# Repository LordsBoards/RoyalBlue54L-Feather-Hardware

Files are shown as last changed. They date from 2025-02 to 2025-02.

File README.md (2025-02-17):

# RoyalBlue54L Feather

An ARM + RISC-V Feather board with the new nRF54L15, built-in debugger, and smart PMIC

<p align="center">
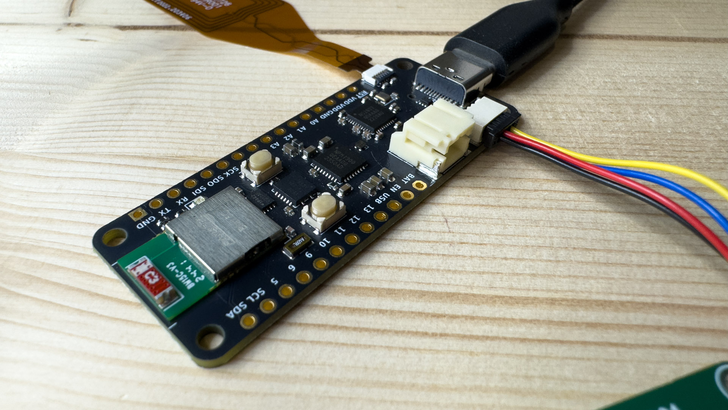
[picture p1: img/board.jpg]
RoyalBlue54L Feather
  
</p>

## Overview

The RoyalBlue54L--familiar Feather formfactor with distinctive features. Nordic's next-gen nRF54L15, an onboard CMSIS-DAP debugger + UART bridge, and smart power-management features from the nPM1300 enable rapid development for your next Bluetooth 6.0, Thread, Matter, Zigbee, Amazon Sidewalk, or proprietary wireless project.

Pre-launch on Crowd Supply - More details coming soon!

## Hardware Features

* Dual-core processing power:
  * ARM Cortex-M33 at 128MHz
  * RISC-V co-processor at 128MHz
* Comprehensive memory configuration:
  * 1.5MB of non-volatile memory (NVM)
  * 256KB of RAM
  * 2MB external flash
* Advanced wireless capabilities:
  * BLE 6.0 support with channel sounding for distance estimation
  * 4Mbps PHY for proprietary wireless protocols
  * 30-50% power reduction compared to nRF52 series
* Integrated development tools:
  * CMSIS-DAP debugger (nRF52833-based)
  * USB-to-UART bridge
  * Open source, Zephyr RTOS-based firmware
* Smart power management:
  * USB-C charging up to 800mA with nPM1300
  * High-accuracy battery fuel gauge
* Connectivity:
  * JST-PH connector
  * STEMMA-QT/Qwiic port
  * NFC antenna connector
* User interfaces:
  * User LED
  * RGB LED (nPM1300-driven)
  * User button
  * Reset button

## Repository Contents

This repository contains the hardware design files for the RoyalBlue54L Feather. The board is designed with KiCAD and includes:

* Schematic files
* PCB layout
* Bill of Materials (BOM)
* Manufacturing files
* Documentation

## Pinout

<p align="center">
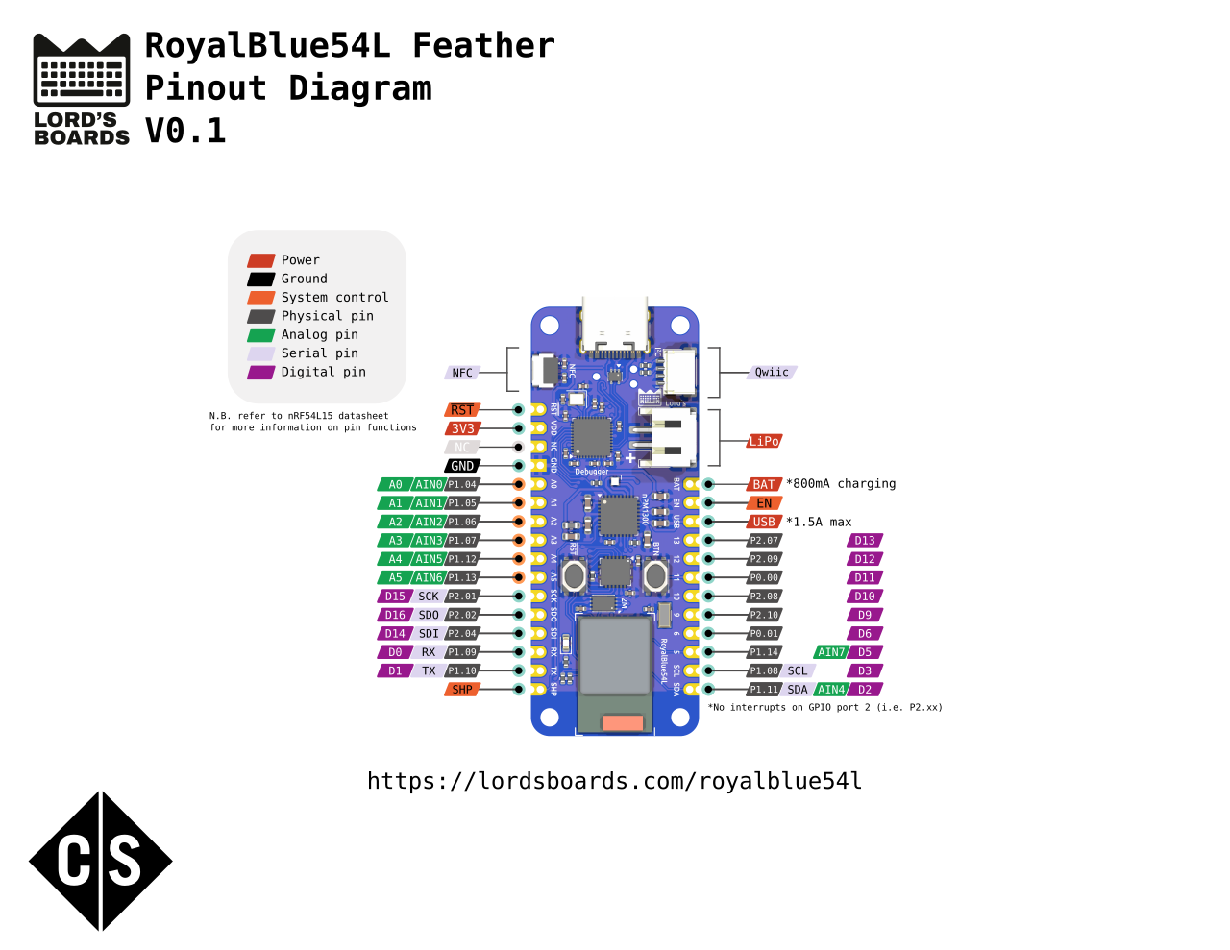
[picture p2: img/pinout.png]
RoyalBlue54L Pinout
    
</p>

## Related Repositories

* [Zephyr Board Support](https://github.com/LordsBoards/RoyalBlue-nRF54L15-Zephyr-Boards)
* [Debugger Firmware](https://github.com/LordsBoards/RoyalBlue-nRF54L15-Debugger-Firmware)

## License

Hardware files are released under CERN-OHL-V2-P.

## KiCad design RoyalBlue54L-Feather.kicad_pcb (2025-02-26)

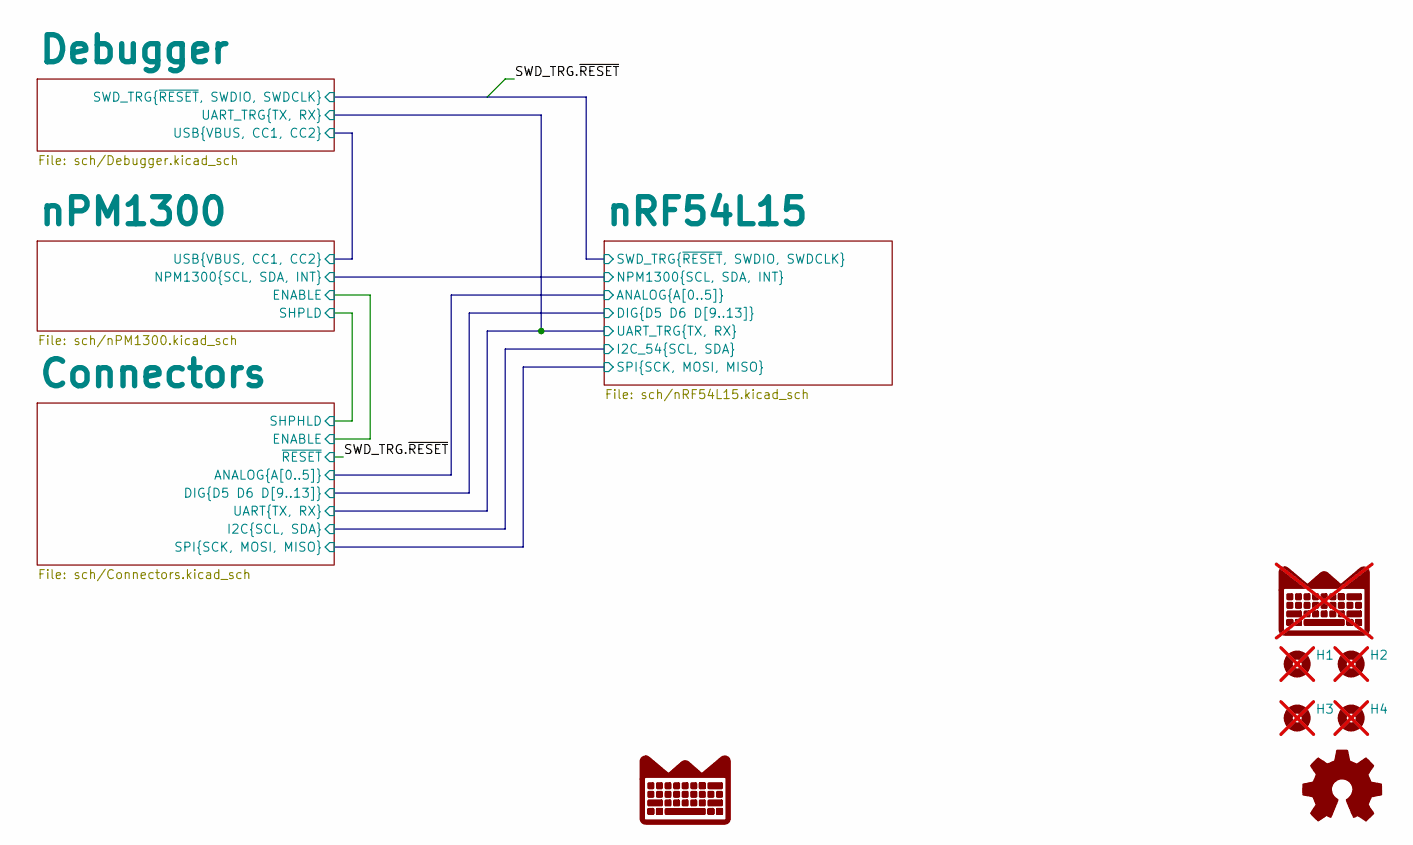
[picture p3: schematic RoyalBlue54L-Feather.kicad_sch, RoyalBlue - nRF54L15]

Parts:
H1, H2, H3, H4: MountingHole; MountingHole_2.5mm; not fitted
LOGO1: LordsBoardsLogo_Small_Silk; not fitted

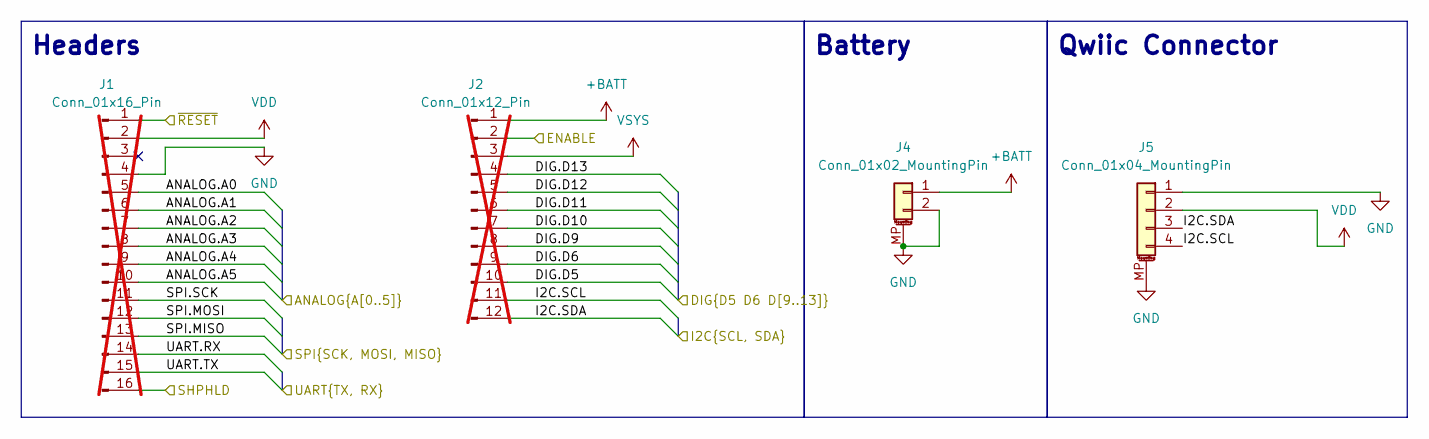
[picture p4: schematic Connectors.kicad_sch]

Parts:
J1: Conn_01x16_Pin; PinHeader_1x16_P2.54mm_Vertical; not fitted
J2: Conn_01x12_Pin; PinHeader_1x12_P2.54mm_Vertical; not fitted
J4: Conn_01x02_MountingPin; JST_PH_S2B-PH-SM4-TB_1x02-1MP_P2.00mm_Horizontal; LCSC C295747
J5: Conn_01x04_MountingPin; JST_SH_SM04B-SRSS-TB_1x04-1MP_P1.00mm_Horizontal; LCSC C3029343

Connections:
+BATT: J2.1, J4.1; also elsewhere on the board
/Connectors/ANALOG.A0: J1.5; also elsewhere on the board
/Connectors/ANALOG.A1: J1.6; also elsewhere on the board
/Connectors/ANALOG.A2: J1.7; also elsewhere on the board
/Connectors/ANALOG.A3: J1.8; also elsewhere on the board
/Connectors/ANALOG.A4: J1.9; also elsewhere on the board
/Connectors/ANALOG.A5: J1.10; also elsewhere on the board
/Connectors/DIG.D5: J2.10; also elsewhere on the board
/Connectors/DIG.D6: J2.9; also elsewhere on the board
/Connectors/DIG.D9: J2.8; also elsewhere on the board
/Connectors/DIG.D10: J2.7; also elsewhere on the board
/Connectors/DIG.D11: J2.6; also elsewhere on the board
/Connectors/DIG.D12: J2.5; also elsewhere on the board
/Connectors/DIG.D13: J2.4; also elsewhere on the board
/Connectors/ENABLE: J2.2; also elsewhere on the board
/Connectors/I2C.SCL: J2.11, J5.4; also elsewhere on the board
/Connectors/I2C.SDA: J2.12, J5.3; also elsewhere on the board
/Connectors/SHPHLD: J1.16; also elsewhere on the board
/Connectors/SPI.MISO: J1.13; also elsewhere on the board
/Connectors/SPI.MOSI: J1.12; also elsewhere on the board
/Connectors/SPI.SCK: J1.11; also elsewhere on the board
/Connectors/UART.RX: J1.14; also elsewhere on the board
/Connectors/UART.TX: J1.15; also elsewhere on the board
/Debugger/SWD_TRG.~RESET: J1.1; also elsewhere on the board
GND: J1.4, J4.2, J4.MP (MountPin), J5.1, J5.MP (MountPin); also elsewhere on the board
VDD: J1.2, J5.2; also elsewhere on the board
VSYS: J2.3; also elsewhere on the board

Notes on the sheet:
Qwiic Connector
Battery
Headers

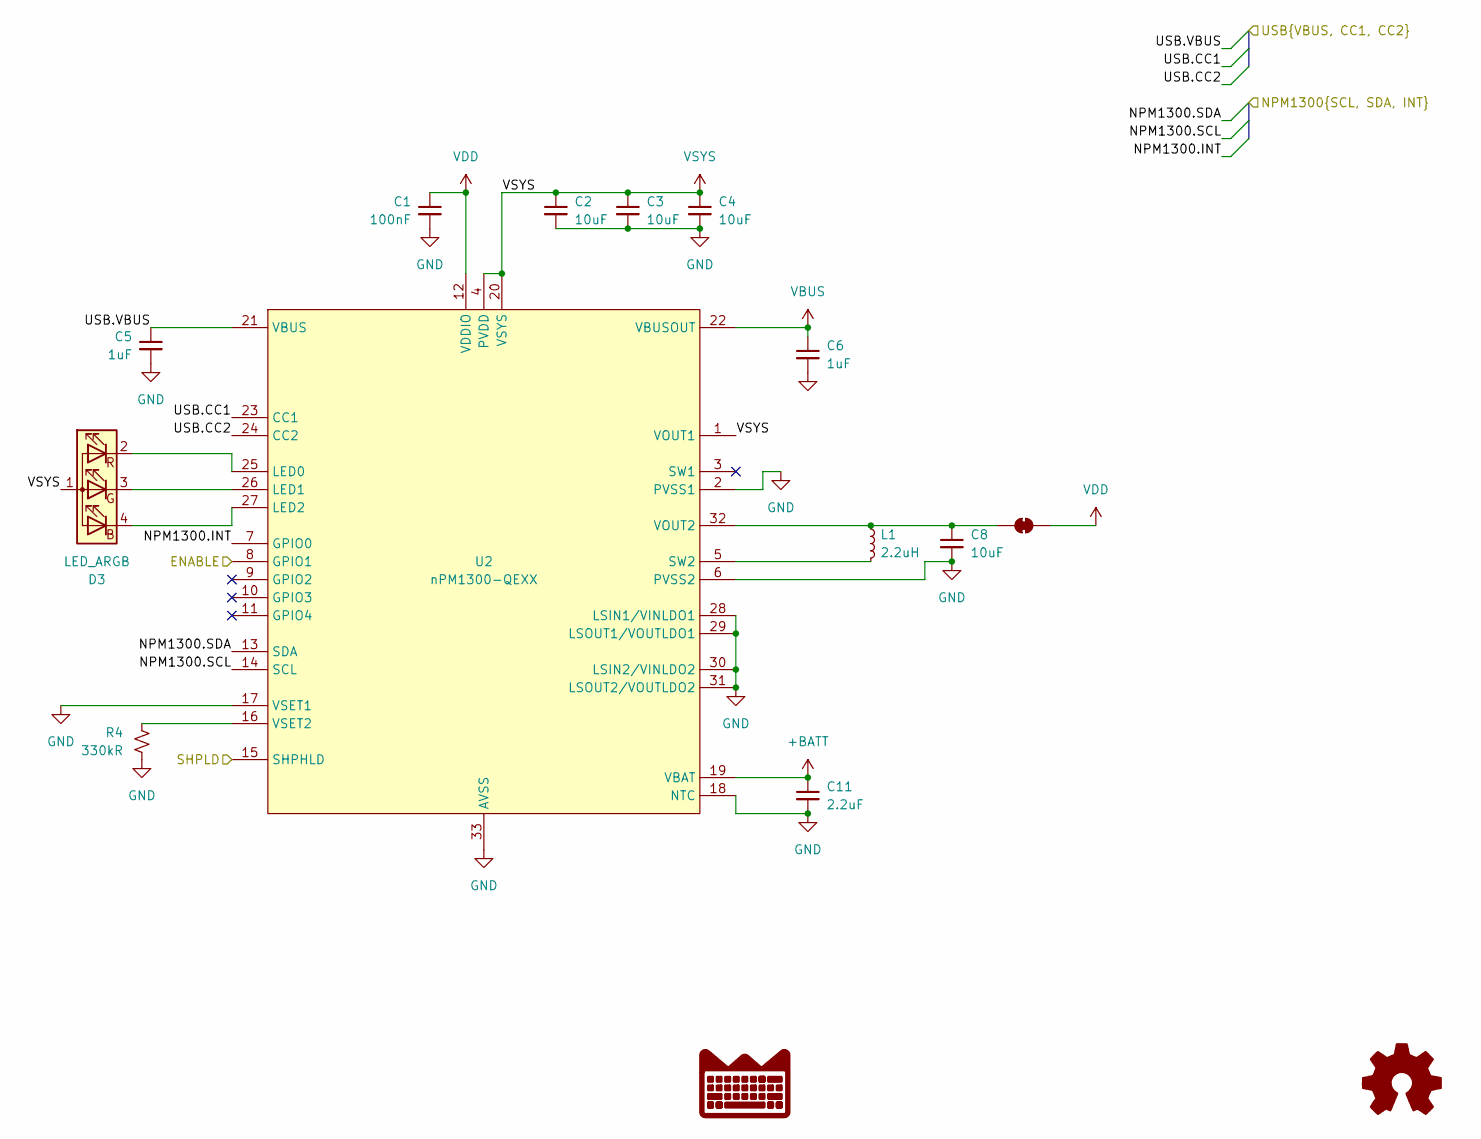
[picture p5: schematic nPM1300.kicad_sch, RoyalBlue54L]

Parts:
C1: 100nF; C_0402_1005Metric; LCSC C307331
C2, C3, C4, C8: 10uF; C_0603_1608Metric; LCSC C96446
C5, C6: 1uF; C_0603_1608Metric; LCSC C15849
C11: 2.2uF; C_0603_1608Metric; LCSC C23630
D3: LED_ARGB; LED_Wurth_150044M155260; LCSC C404280
JP1: SolderJumper_2_Bridged; SolderJumper-2_P1.3mm_Bridged_RoundedPad1.0x1.5mm
L1: 2.2uH; L_0603_1608Metric; LCSC C337910
R4: 330kR; R_0402_1005Metric; LCSC C25778
U2: nPM1300-QEXX; QFN-32-1EP_5x5mm_P0.5mm_EP3.6x3.6mm_ThermalVias; LCSC C7466043

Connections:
+BATT: C11.1, U2.19 (VBAT); also elsewhere on the board
/Connectors/ENABLE: U2.8 (GPIO1); also elsewhere on the board
/Connectors/SHPHLD: U2.15 (SHPHLD); also elsewhere on the board
/Debugger/USB.CC1: U2.23 (CC1); also elsewhere on the board
/Debugger/USB.CC2: U2.24 (CC2); also elsewhere on the board
/Debugger/USB.VBUS: C5.1, U2.21 (VBUS); also elsewhere on the board
/nPM1300/NPM1300.INT: U2.7 (GPIO0); also elsewhere on the board
/nPM1300/NPM1300.SCL: U2.14 (SCL); also elsewhere on the board
/nPM1300/NPM1300.SDA: U2.13 (SDA); also elsewhere on the board
GND: C1.2, C2.2, C3.2, C4.2, C5.2, C6.2, C8.2, C11.2, R4.2, U2.2 (PVSS1), U2.6 (PVSS2), U2.17 (VSET1), U2.18 (NTC), U2.28 (LSIN1/VINLDO1), U2.29 (LSOUT1/VOUTLDO1), U2.30 (LSIN2/VINLDO2), U2.31 (LSOUT2/VOUTLDO2), U2.33 (AVSS); also elsewhere on the board
unnamed: D3.4 (BK), U2.27 (LED2)
unnamed: D3.3 (GK), U2.26 (LED1)
unnamed: D3.2 (RK), U2.25 (LED0)
unnamed: C8.1, JP1.1 (A), L1.1, U2.32 (VOUT2)
unnamed: L1.2, U2.5 (SW2)
unnamed: R4.1, U2.16 (VSET2)
VBUS: C6.1, U2.22 (VBUSOUT); also elsewhere on the board
VDD: C1.1, JP1.2 (B), U2.12 (VDDIO); also elsewhere on the board
VSYS: C2.1, C3.1, C4.1, D3.1 (A), U2.1 (VOUT1), U2.4 (PVDD), U2.20 (VSYS); also elsewhere on the board

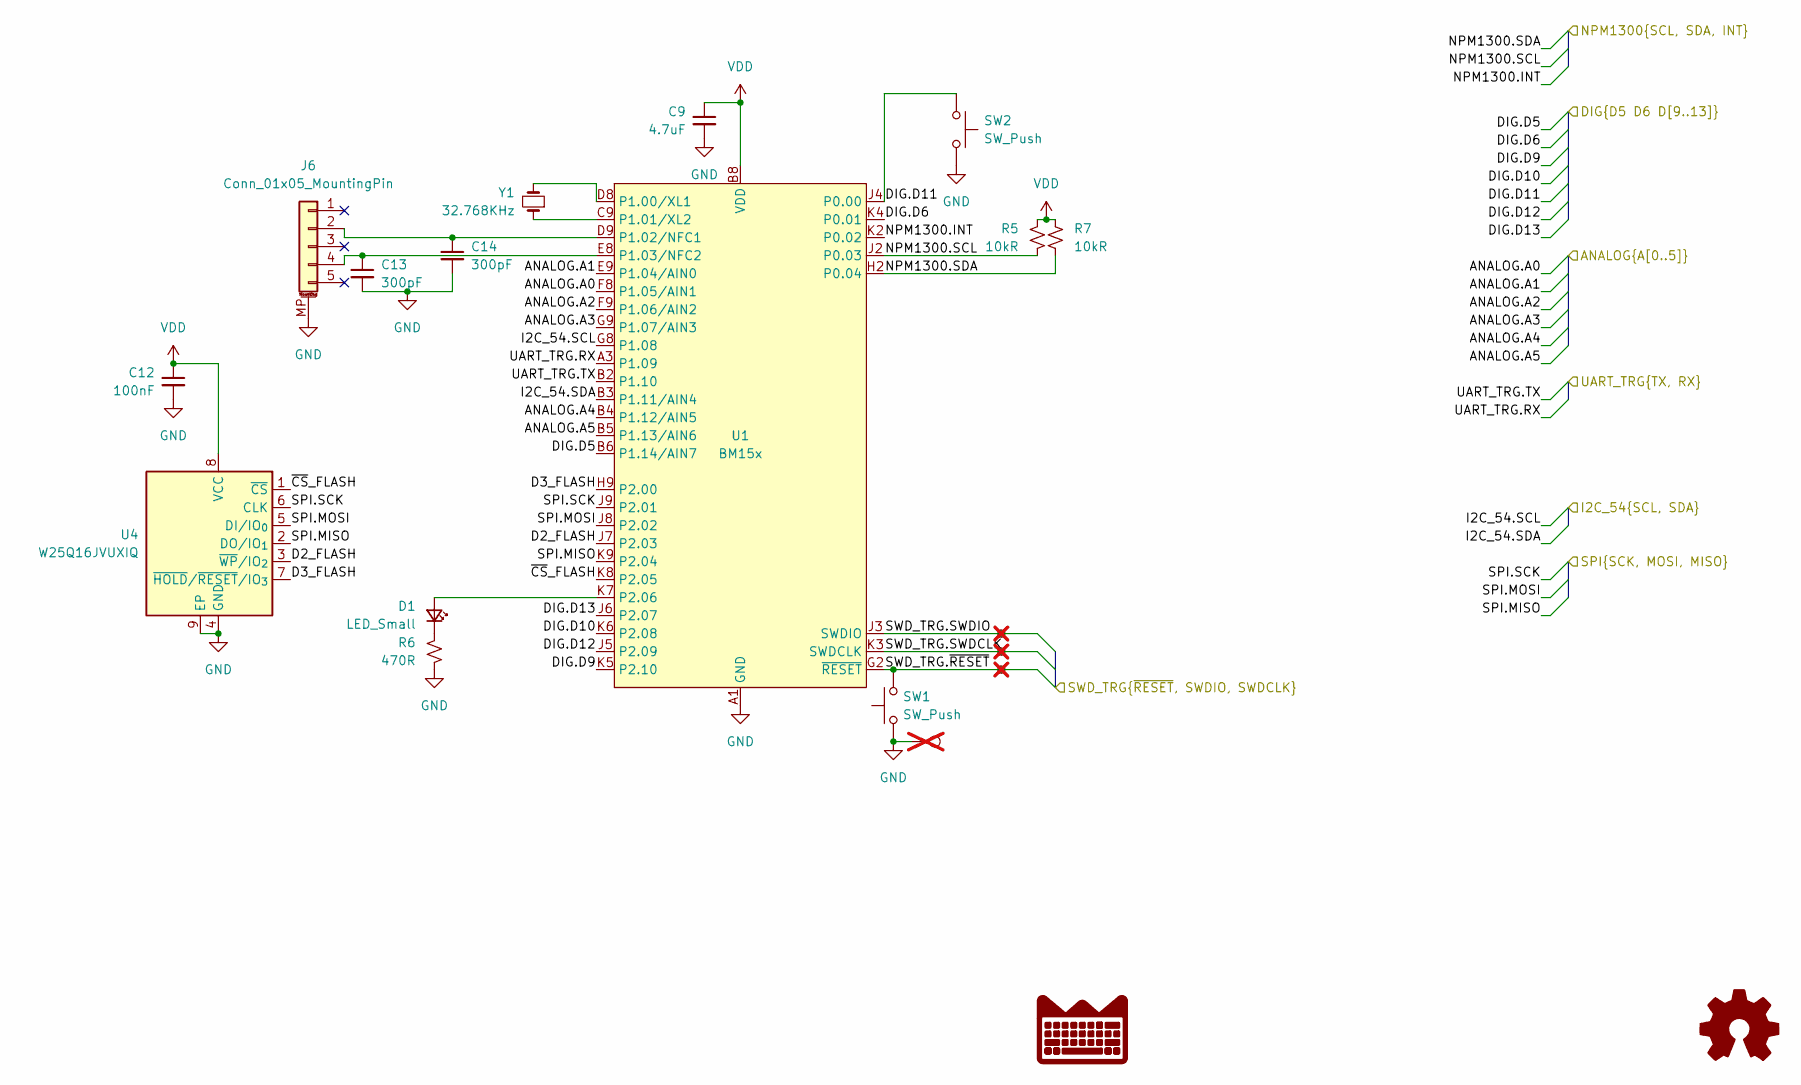
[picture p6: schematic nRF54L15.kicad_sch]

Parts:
C9: 4.7uF; C_0402_1005Metric; LCSC C23733
C12: 100nF; C_0402_1005Metric; LCSC C307331
C13, C14: 300pF; C_0402_1005Metric; LCSC C126505
D1: LED_Small; LED_0603_1608Metric; LCSC C125103
J6: Conn_01x05_MountingPin; CONN-SMD_5P-P0.50_HCTL_HC-FPC-05-09-5RLTAG; LCSC C5213747
R5, R7: 10kR; R_0402_1005Metric; LCSC C25744
R6: 470R; R_0402_1005Metric; LCSC C25117
SW1, SW2: SW_Push; SW_Push_1P1T_NO_Vertical_Wuerth_434133025816; LCSC C139797
TP1, TP2, TP3, TP4: TestPoint; TestPoint_Pad_D2.0mm; not fitted
U1: BM15x; BM15x-LGA-45_15.8x10mm; LCSC C9900148376
U4: W25Q16JVUXIQ; Winbond_USON-8-1EP_3x2mm_P0.5mm_EP0.2x1.6mm; LCSC C2843335
Y1: 32.768KHz; Crystal_SMD_3215-2Pin_3.2x1.5mm; LCSC C32346

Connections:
/Connectors/ANALOG.A0: U1.F8 (P1.05/AIN1); also elsewhere on the board
/Connectors/ANALOG.A1: U1.E9 (P1.04/AIN0); also elsewhere on the board
/Connectors/ANALOG.A2: U1.F9 (P1.06/AIN2); also elsewhere on the board
/Connectors/ANALOG.A3: U1.G9 (P1.07/AIN3); also elsewhere on the board
/Connectors/ANALOG.A4: U1.B4 (P1.12/AIN5); also elsewhere on the board
/Connectors/ANALOG.A5: U1.B5 (P1.13/AIN6); also elsewhere on the board
/Connectors/DIG.D5: U1.B6 (P1.14/AIN7); also elsewhere on the board
/Connectors/DIG.D6: U1.K4 (P0.01); also elsewhere on the board
/Connectors/DIG.D9: U1.K5 (P2.10); also elsewhere on the board
/Connectors/DIG.D10: U1.K6 (P2.08); also elsewhere on the board
/Connectors/DIG.D11: SW2.1, U1.J4 (P0.00); also elsewhere on the board
/Connectors/DIG.D12: U1.J5 (P2.09); also elsewhere on the board
/Connectors/DIG.D13: U1.J6 (P2.07); also elsewhere on the board
/Connectors/I2C.SCL: U1.G8 (P1.08); also elsewhere on the board
/Connectors/I2C.SDA: U1.B3 (P1.11/AIN4); also elsewhere on the board
/Connectors/SPI.MISO: U1.K9 (P2.04), U4.2 (DO/IO_{1}); also elsewhere on the board
/Connectors/SPI.MOSI: U1.J8 (P2.02), U4.5 (DI/IO_{0}); also elsewhere on the board
/Connectors/SPI.SCK: U1.J9 (P2.01), U4.6 (CLK); also elsewhere on the board
/Connectors/UART.RX: U1.A3 (P1.09); also elsewhere on the board
/Connectors/UART.TX: U1.B2 (P1.10); also elsewhere on the board
/Debugger/SWD_TRG.SWDCLK: TP3.1, U1.K3 (SWDCLK); also elsewhere on the board
/Debugger/SWD_TRG.SWDIO: TP1.1, U1.J3 (SWDIO); also elsewhere on the board
/Debugger/SWD_TRG.~RESET: SW1.2, TP2.1, U1.G2 (~RESET); also elsewhere on the board
/nPM1300/NPM1300.INT: U1.K2 (P0.02); also elsewhere on the board
/nPM1300/NPM1300.SCL: R5.2, U1.J2 (P0.03); also elsewhere on the board
/nPM1300/NPM1300.SDA: R7.2, U1.H2 (P0.04); also elsewhere on the board
/nRF54L15/D2_FLASH: U1.J7 (P2.03), U4.3 (~WP/IO_{2})
/nRF54L15/D3_FLASH: U1.H9 (P2.00), U4.7 (~HOLD/~RESET/IO_{3})
/nRF54L15/~CS_FLASH: U1.K8 (P2.05), U4.1 (~CS)
GND: C9.2, C12.2, C13.2, C14.2, J6.MP (MountPin), R6.2, SW1.1, SW2.2, TP4.1, U1.A1 (GND), U1.A9 (GND), U1.B1 (GND), U1.B7 (GND), U1.B9 (GND), U1.D1 (GND), U1.E1 (GND), U1.F1 (GND), U1.H8 (GND), U4.4 (GND), U4.9 (EP); also elsewhere on the board
unnamed: D1.2 (A), U1.K7 (P2.06)
unnamed: D1.1 (K), R6.1
unnamed: C14.1, J6.2, U1.D9 (P1.02/NFC1)
unnamed: C13.1, J6.4, U1.E8 (P1.03/NFC2)
unnamed: U1.D8 (P1.00/XL1), Y1.2
unnamed: U1.C9 (P1.01/XL2), Y1.1
VDD: C9.1, C12.1, R5.1, R7.1, U1.B8 (VDD), U1.C8 (VDD), U4.8 (VCC); also elsewhere on the board

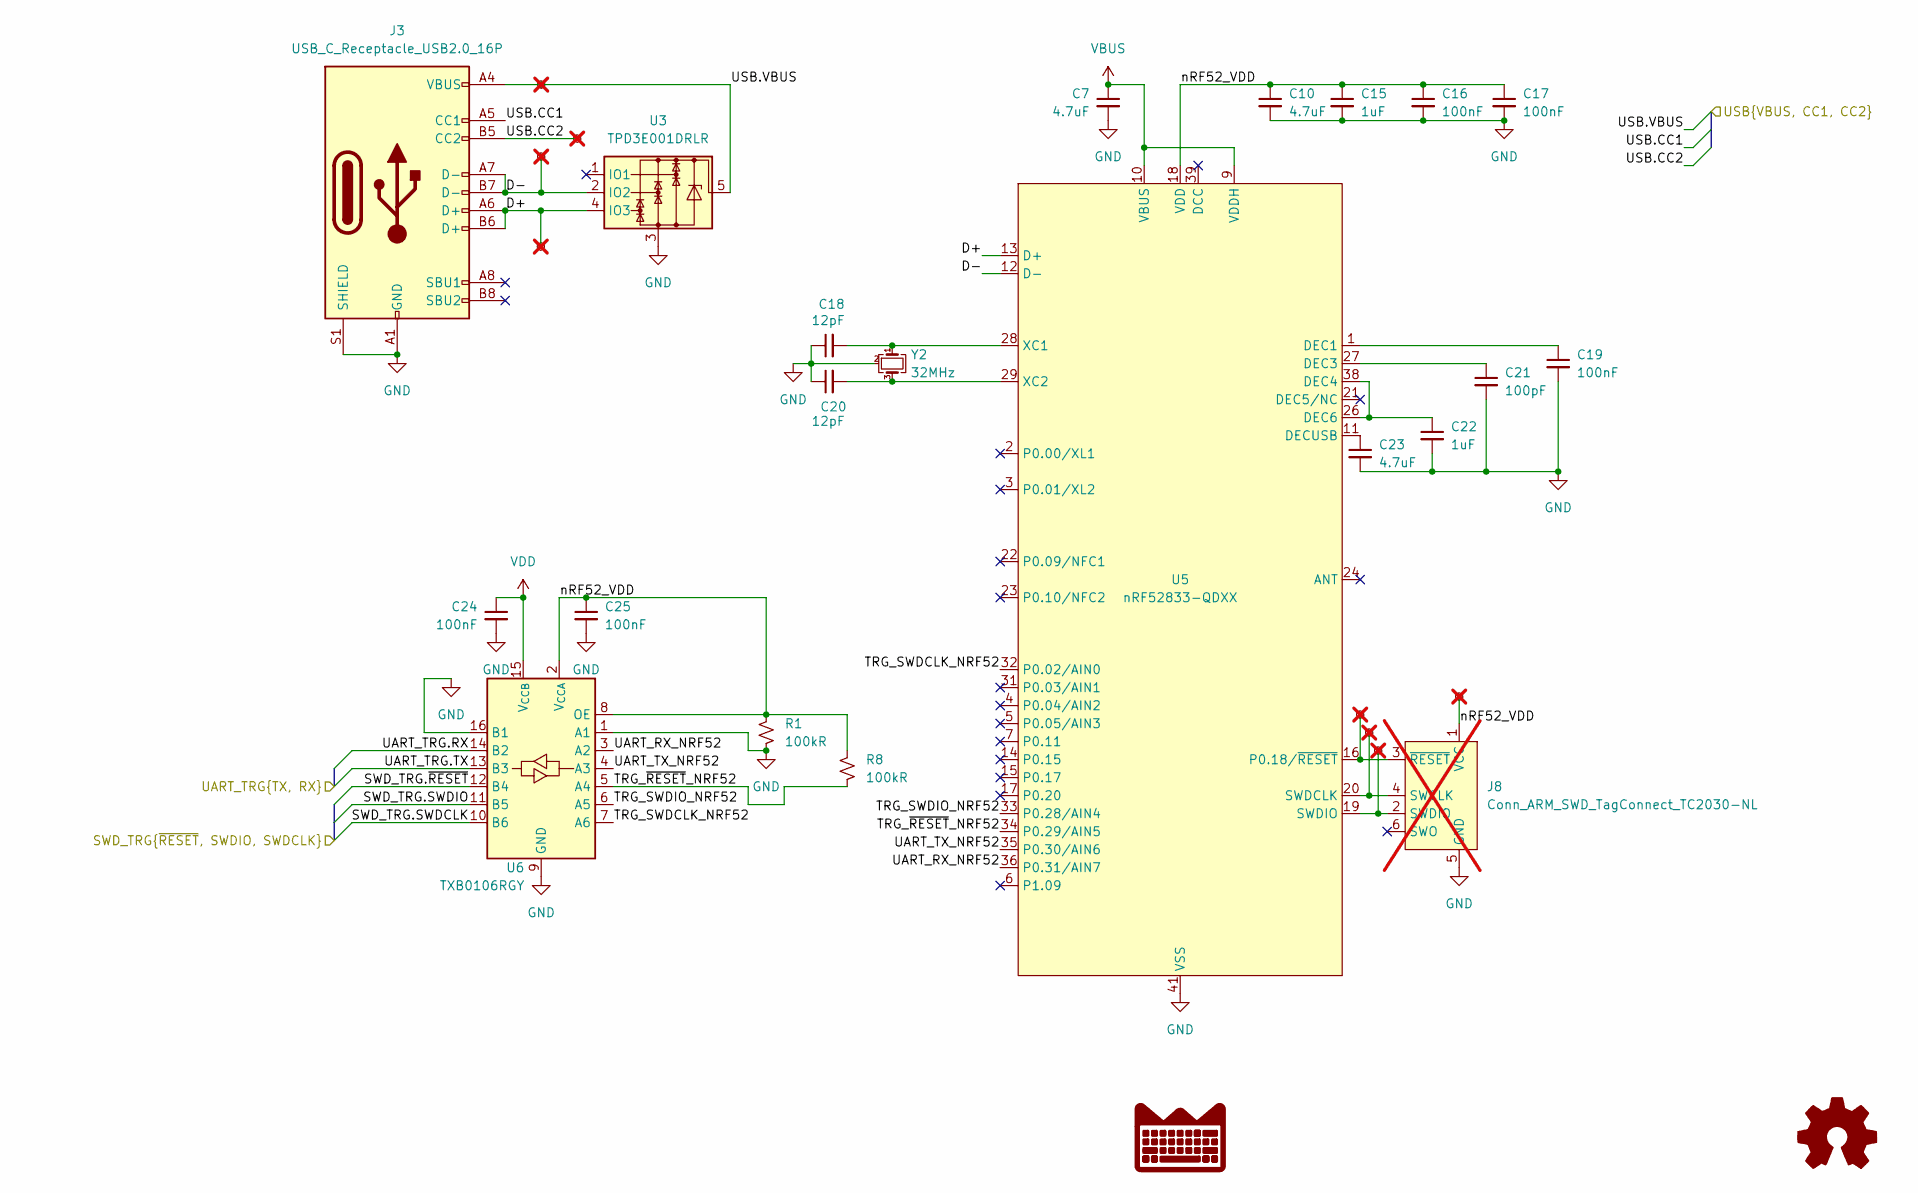
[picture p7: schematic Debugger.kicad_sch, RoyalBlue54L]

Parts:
C7, C10, C23: 4.7uF; C_0402_1005Metric; LCSC C23733
C15, C22: 1uF; C_0402_1005Metric; LCSC C52923
C16, C17, C19, C24, C25: 100nF; C_0402_1005Metric; LCSC C307331
C18, C20: 12pF; C_0402_1005Metric; LCSC C1547
C21: 100pF; C_0402_1005Metric; LCSC C1546
J3: USB_C_Receptacle_USB2.0_16P; USB_C_Receptacle_HRO_TYPE-C-31-M-12; LCSC C165948
J8: Conn_ARM_SWD_TagConnect_TC2030-NL; Tag-Connect_TC2030-IDC-NL_2x03_P1.27mm_Vertical; not fitted
R1, R8: 100kR; R_0402_1005Metric; LCSC C25741
TP5, TP6, TP7, TP8, TP9, TP10, TP11, TP12: TestPoint; TestPoint_Pad_D1.5mm; not fitted
U3: TPD3E001DRLR; SOT-553; LCSC C2999113
U5: nRF52833-QDXX; QFN-40-1EP_5x5mm_P0.4mm_EP3.6x3.6mm_ThermalVias; LCSC C2895249
U6: TXB0106RGY; Texas_RGY_R-PVQFN-N16_EP2.05x2.55mm; LCSC C2652978
Y2: 32MHz; Crystal_SMD_2016-4Pin_2.0x1.6mm; LCSC C2682773

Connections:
/Connectors/UART.RX: U6.14 (B2); also elsewhere on the board
/Connectors/UART.TX: U6.13 (B3); also elsewhere on the board
/Debugger/D+: J3.A6 (D+), J3.B6 (D+), TP7.1, U3.4 (IO3), U5.13 (D+)
/Debugger/D-: J3.A7 (D-), J3.B7 (D-), TP8.1, U3.2 (IO2), U5.12 (D-)
/Debugger/SWD_TRG.SWDCLK: U6.10 (B6); also elsewhere on the board
/Debugger/SWD_TRG.SWDIO: U6.11 (B5); also elsewhere on the board
/Debugger/SWD_TRG.~RESET: U6.12 (B4); also elsewhere on the board
/Debugger/TRG_SWDCLK_NRF52: U5.32 (P0.02/AIN0), U6.7 (A6)
/Debugger/TRG_SWDIO_NRF52: U5.33 (P0.28/AIN4), U6.6 (A5)
/Debugger/TRG_~RESET_NRF52: R8.2, U5.34 (P0.29/AIN5), U6.5 (A4)
/Debugger/UART_RX_NRF52: U5.36 (P0.31/AIN7), U6.3 (A2)
/Debugger/UART_TX_NRF52: U5.35 (P0.30/AIN6), U6.4 (A3)
/Debugger/USB.CC1: J3.A5 (CC1); also elsewhere on the board
/Debugger/USB.CC2: J3.B5 (CC2), TP6.1; also elsewhere on the board
/Debugger/USB.VBUS: J3.A4 (VBUS), J3.A9 (VBUS), J3.B4 (VBUS), J3.B9 (VBUS), TP5.1, U3.5; also elsewhere on the board
/Debugger/nRF52_VDD: C10.1, C15.1, C16.1, C17.1, C25.1, J8.1 (VCC), R1.1, R8.1, TP9.1, U5.8 (VDD), U5.18 (VDD), U5.30 (VDD), U5.40 (VDD), U6.2 (V_{CCA}), U6.8 (OE)
GND: C7.2, C10.2, C15.2, C16.2, C17.2, C18.1, C19.2, C20.1, C21.2, C22.2, C23.2, C24.2, C25.2, J3.A1 (GND), J3.A12 (GND), J3.B1 (GND), J3.B12 (GND), J3.S1 (SHIELD), J8.5 (GND), R1.2, U3.3, U5.25 (VSS_PA), U5.37 (VSS), U5.41 (VSS), U6.1 (A1), U6.9 (GND), U6.16 (B1), U6.17 (GND), Y2.2, Y2.4; also elsewhere on the board
unnamed: J8.4 (SWCLK), TP11.1, U5.20 (SWDCLK)
unnamed: J8.2 (SWDIO), TP12.1, U5.19 (SWDIO)
unnamed: J8.3 (~RESET), TP10.1, U5.16 (P0.18/~RESET)
unnamed: C19.1, U5.1 (DEC1)
unnamed: C21.1, U5.27 (DEC3)
unnamed: C22.1, U5.26 (DEC6), U5.38 (DEC4)
unnamed: C23.1, U5.11 (DECUSB)
unnamed: C18.2, U5.28 (XC1), Y2.1
unnamed: C20.2, U5.29 (XC2), Y2.3
VBUS: C7.1, U5.9 (VDDH), U5.10 (VBUS); also elsewhere on the board
VDD: C24.1, U6.15 (V_{CCB}); also elsewhere on the board

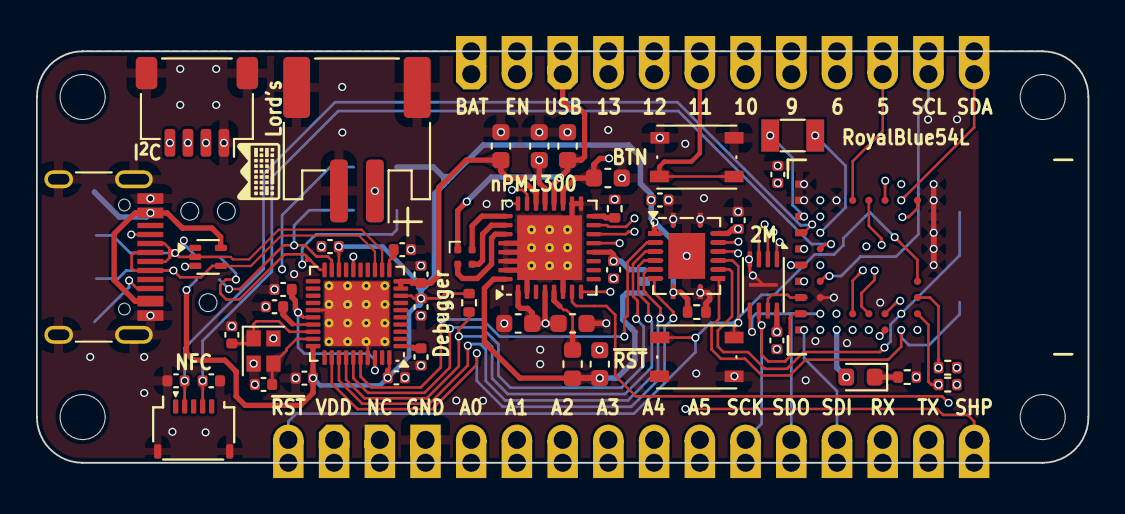
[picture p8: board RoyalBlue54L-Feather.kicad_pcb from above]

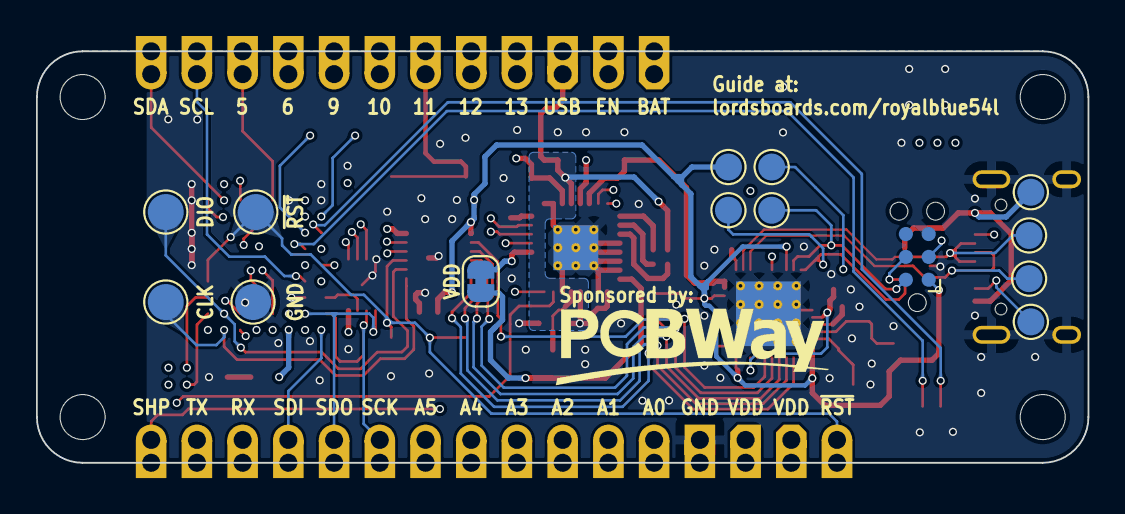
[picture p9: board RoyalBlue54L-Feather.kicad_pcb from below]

Board: 8 copper layers, 58.4 x 22.9 mm, 70 parts (16 on the bottom side), 68 nets.

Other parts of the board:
Ref**: Val**; PCBWayLogo

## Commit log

2025-01-26 Initial commit.
    [RoyalBlue-nRF54L15.kicad_pcb, RoyalBlue-nRF54L15.kicad_sch, USB.kicad_sch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]
2025-02-04 Updated 02/03/25
    [Connectors.kicad_sch, Debugger.kicad_sch, RoyalBlue-nRF54L15.kicad_pcb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]
2025-02-04 Renamed to RoyalBlue54L-Feather
    [Connectors.kicad_sch, Debugger.kicad_sch, RoyalBlue54L-Feather.kicad_pcb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]
2025-02-04 JLCPCB files and README
    [RoyalBlue54L-Feather-CuBottom.gbr, RoyalBlue54L-Feather-CuIn1.gbr, RoyalBlue54L-Feather-CuIn2.gbr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]
2025-02-04 Added NFC antenna hardware repo
    [RoyalBlue54L-NFC-Antenna-CuBottom.gbr, RoyalBlue54L-NFC-Antenna-CuTop.gbr, RoyalBlue54L-NFC-Antenna-EdgeCuts.gbr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]
2025-02-12 Added testpoints, moved USB connection to VSYS.
    [Connectors.kicad_sch, Debugger.kicad_sch, RoyalBlue54L-Feather.kicad_pcb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]
2025-02-15 Updated to include castellations, more testpoints
    [Debugger.kicad_sch, RoyalBlue54L-Feather.kicad_pcb, nRF54L15.kicad_sch]
2025-02-17 Adjusted pinout, added pinout diagram
    [Connectors.kicad_sch, Debugger.kicad_sch, RoyalBlue54L-Feather.kicad_pcb]
2025-02-20 Revert changes to vias, DRC fixes
    [Debugger.kicad_sch, RoyalBlue54L-Feather.kicad_pcb]
2025-02-20 Removed JLCPCB files
    [RoyalBlue54L-Feather-CuBottom.gbr, RoyalBlue54L-Feather-CuIn1.gbr, RoyalBlue54L-Feather-CuIn2.gbr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]
2025-02-20 Updated all vias to share size, fixed zone fill outlines
    [Debugger.kicad_sch, RoyalBlue54L-Feather.kicad_pcb, nRF54L15.kicad_sch]
2025-02-25 Fixed DRC errors
    [Debugger.kicad_sch, RoyalBlue54L-Feather.kicad_pcb, nRF54L15.kicad_sch]
2025-02-26 Added PCBWay logo
    [Debugger.kicad_sch, RoyalBlue54L-Feather.kicad_pcb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]
